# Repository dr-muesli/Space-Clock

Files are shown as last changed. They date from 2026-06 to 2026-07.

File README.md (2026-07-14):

# Space-Clock
**Program code and build guide for the space clock.**

**The space clock is a matrix clock in which the time is determined by counting the number of illuminated light squares.**

---

## Materials

- IKEA Rödalm picture frame (13x18 cm)  
- WS2812B NeoPixel LED strip (60 LEDs/m)  
  - 3 to 5 strips with 9 LEDs each  
- ESP32 (recommended: ESP32-S2 Mini)  
- 3D-printed front panel  
- USB cable compatible with your ESP  

---

## Assembly Instructions

### 1. Prepare the Back Panel

Mark the layout on the back panel of the frame:

- Draw a cross to find the center (vertical and horizontal middle lines)  
- Add additional horizontal lines for each LED row  
- Keep equal spacing between rows (matching the LED spacing)  
- Minimum: **3 rows**  
- Recommended: **5 rows** (for more visual effects)

---

### 2. Attach LED Strips

⚠️ Pay attention to the **data direction** of the LED strips!

- With 5 rows:
  - Start at the bottom row  
  - Attach the strip **from right to left**  
  - Continue each row above in the same direction  

- Solder 3 wires (VCC, GND, DATA) to the **input side** of the bottom strip (left side)

- Connect each strip to the one above it at the ends (daisy chain)

---

### 3. Mount the ESP32

- Attach the ESP32 to the back of the frame  
- Connect:
  - **VCC**
  - **GND**
  - **DATA** (to a suitable GPIO pin)

---

## Programming

*(coming soon)*

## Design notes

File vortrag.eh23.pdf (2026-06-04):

S.p.a.c.e. U.h.r.

# SpaceUhr

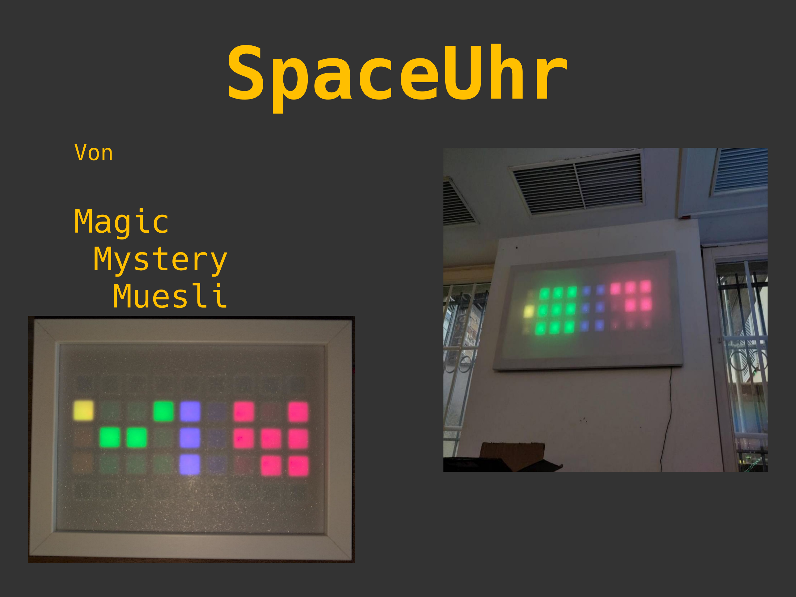
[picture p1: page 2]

Von

## Magic Mystery Muesli

# Magic Mystery Muesli

## - HAXKO - technikbegeisteter Elektroingenieur - PLC, KNX, Softwareentwickung

## - https://woof.tech/@dr_muesli

# butzel

## - HAXKO & LUG-MYK - FIAE & IT-Berater

## - Python, C, Java,VFP

## - GNU/Linux (Gentoo) - Pentester (RedTeamer)

# SpaceUhr

## - Idee nach der Tix-Uhr - alternative Darstellungs-arten

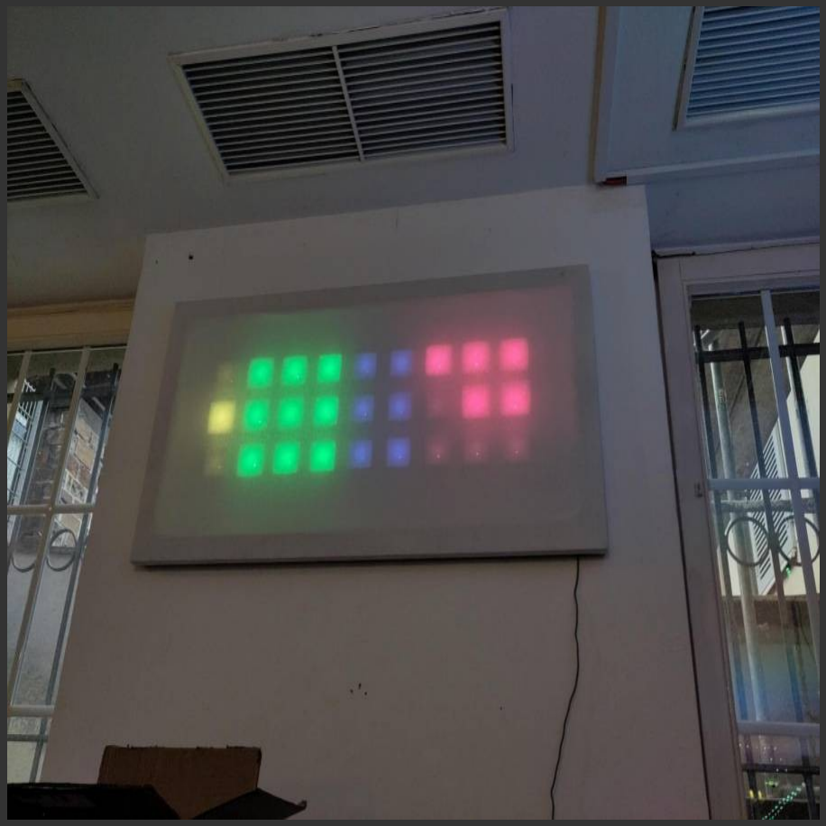
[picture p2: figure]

# SpaceUhr: Funktionsweise

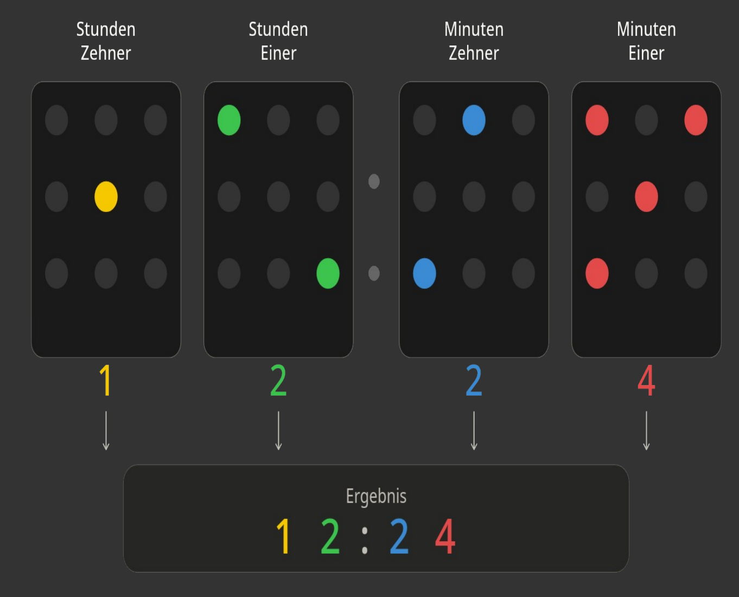
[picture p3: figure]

## - keine BinärUhr - Leuchtpunkte zählen

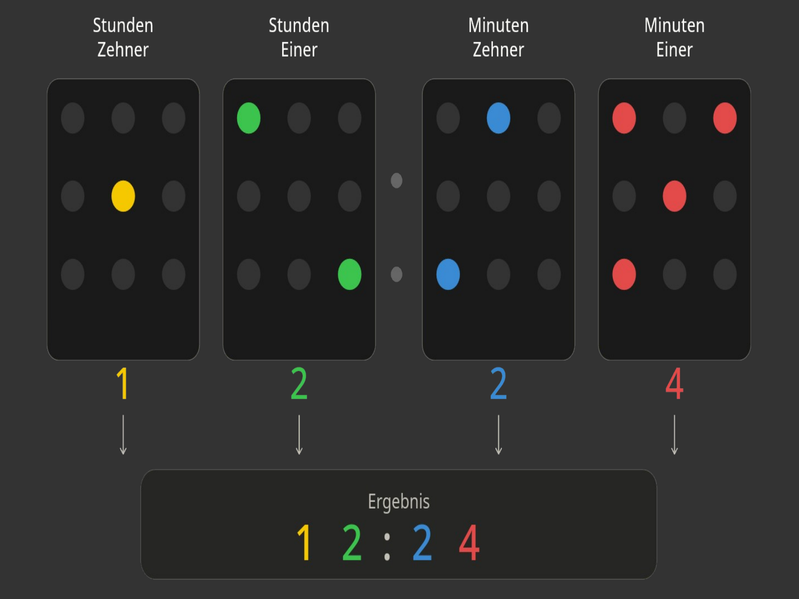
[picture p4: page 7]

# SpaceUhr@EH23

## - verkleinert

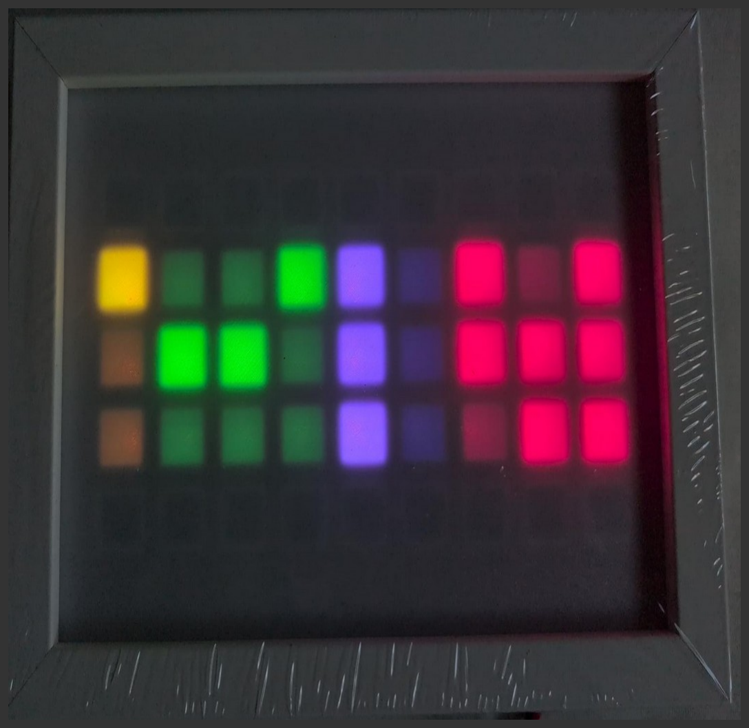
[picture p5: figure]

## - Bilderrahmen „Rödalm“

- 5-zeilig (45 NeoPixel)

## - kein Taster

- ca. 15-20€

# SpaceUhr: BoM

## - Bilderrahmen „Rödalm“

## - 5-Streifen NeoPixel - ESP32 - 3D-Druck - Kabel

# SpaceUhr: Aufbau I

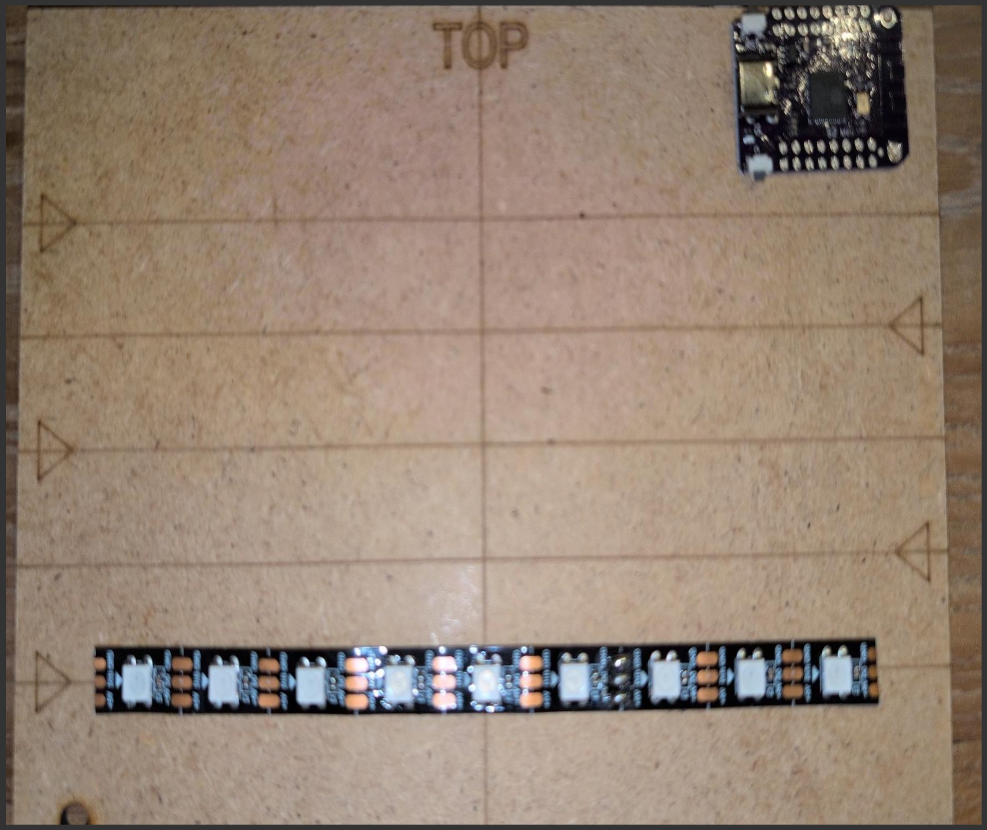
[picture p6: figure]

## - NeoPixel

(selbstklebend)

## - Bilderrahmen

Pfeilrichtung
beachten!

# SpaceUhr: Aufbau I

## - NeoPixel

(selbstklebend)

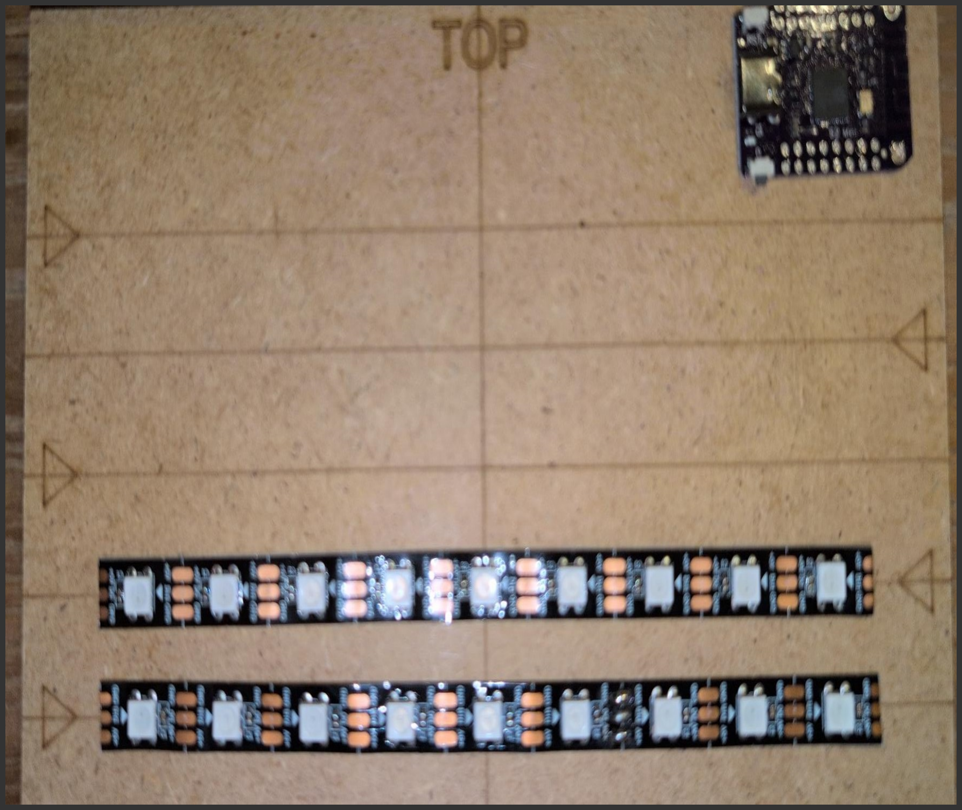
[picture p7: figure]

## - Bilderrahmen

Pfeilrichtung
beachten!

# SpaceUhr: Aufbau II

## - NeoPixel

(selbstklebend)

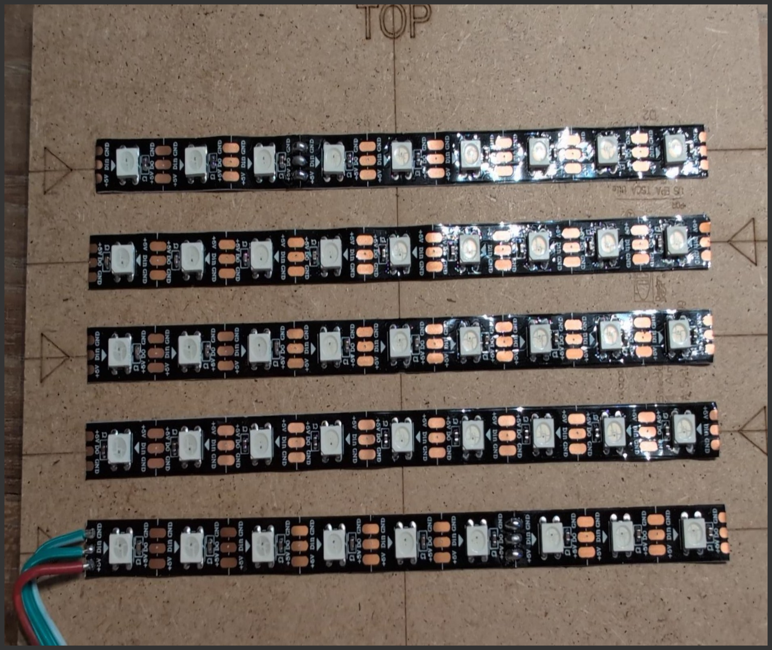
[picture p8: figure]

## - Bilderrahmen - Kabel

Beschriftung
beachten!

# SpaceUhr: Aufbau II

## - NeoPixel

(selbstklebend)

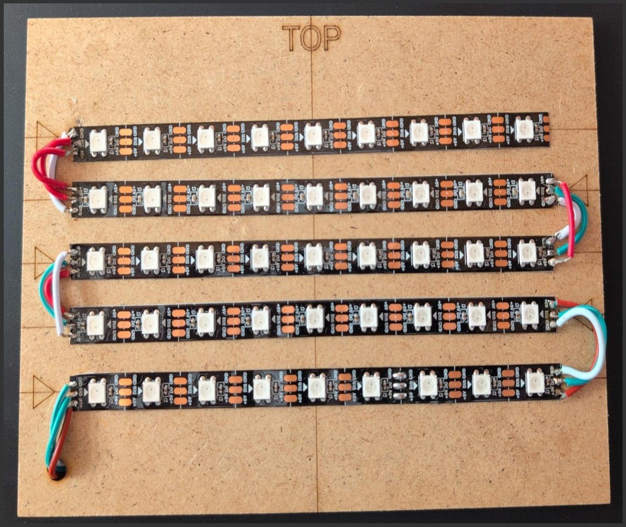
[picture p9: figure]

## - Bilderrahmen - Kabel

Beschriftung
beachten!

# SpaceUhr: Aufbau III

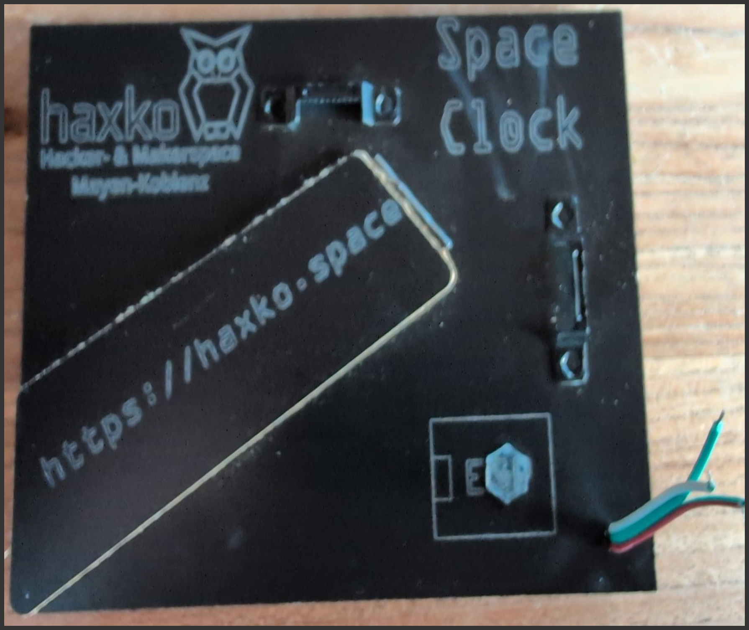
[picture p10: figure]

## - Bilderrahmen - ESP32

Pin 16: DATA
Pin GND: GND
Pin VBUS: 5V

# SpaceUhr: Aufbau III

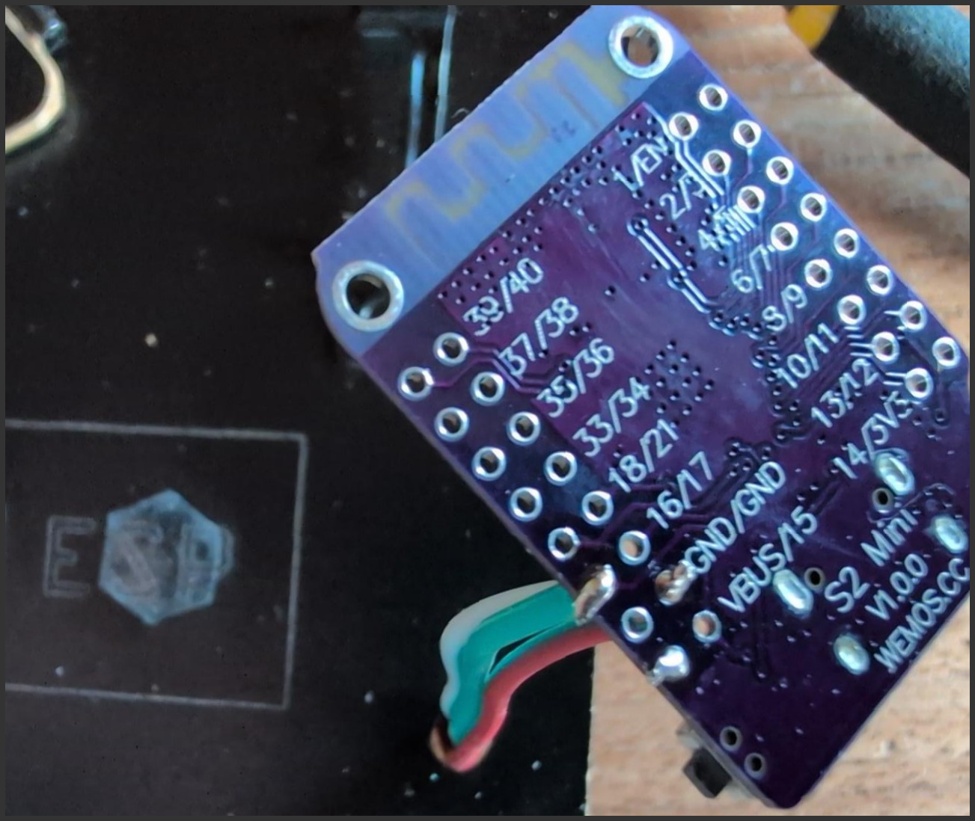
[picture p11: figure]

## - Bilderrahmen - ESP32

Pin 16: DATA
Pin GND: GND
Pin VBUS: 5V

# SpaceUhr: Aufbau III

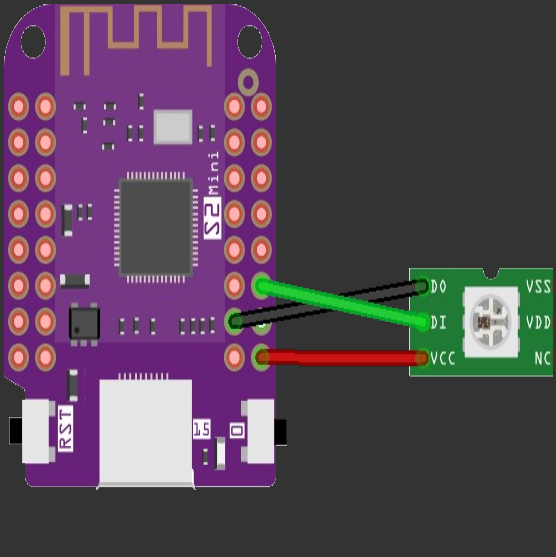
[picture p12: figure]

## - Bilderrahmen - ESP32

Pin 16: DATA
Pin GND: GND
Pin VBUS: 5V

# SpaceUhr: Flashen

## - ESP32 - esptool bzw. esptool.py

# boot-Taster gedrückt halten & USB verbinden

# boot-Taster lösen

esptool --no-stub --port /dev/ttyUSB0 erase_flash
esptool --no-stub --port /dev/ttyACM0 write_flash 0x1000 µpython.bin

# SpaceUhr: thonny

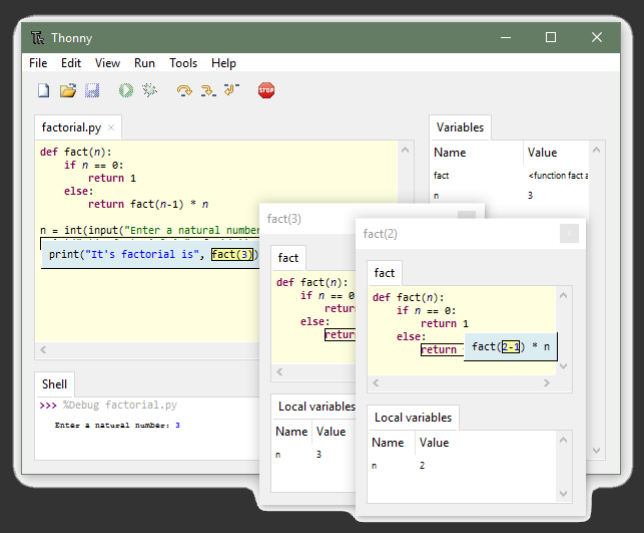
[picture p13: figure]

CC BY-SA 4.0
https://commons.wikimedia.org/wiki/File:Thonny2_0_screenshot_windows_10.pn gg

# SpaceUhr: Programmieren

## - thonny

– Menüpunkt: | run
– Reiter: | interpreter
– DropDown: | MicroPython (ESP32)

### – [strg]+[F2]

# SpaceUhr: main.py

## - thonny

– Menüpunkt: | File/Open
– Dialog: | This computer
– Datei: | main.py

# SpaceUhr: main.py

## - thonny

– Menüpunkt: | File/Save As...
– Dialog: | MicroPython device
– Datei: | main.py

# SpaceUhr: wlan_data.py

## - thonny

– Menüpunkt: | File/Open
– Dialog: | MicroPython device
– Datei: | wlan_data.py

# SpaceUhr: wlan_data.py (anpassen)

## - wlan_data.py

WLAN_NETZE = [
("essid", "<password>"),
("freifunk-myk.de", ""),
("example", "easterhegg2026"), ]

# SpaceUhr: wlan_data.py

## - thonny

– Menüpunkt: | File/Save As...
– Dialog: | MicroPython device
– Datei: | wlan_data.py

# SpaceUhr: MicroPython

## - Erlaeuterung (aus mp-workshop: 11) - Besonderheiten (aus mp-workshop:

27)

## - Flashen (aus mp-workshop: 15) - Verbinden (aus mp-workshop: 31)

●

# SpaceUhr: import abc.py

## - Font-Library: abc.py

import abc

## - setPixel(x, y, rgb, pin)

setPixel(2,4, (7,14,21), 16)

## - write(str, rgb, pin)

write(“Hi“, (7,14,21), 16)

## - marquee(str, rgb, delay, loops, pin)

marquee(“haxko.space“, (7,7,7), 0.2, 5, 16)

# :> MicroPython

:: Python 3
:- Mikrocontroller
:- Embedded Systems

:: Damien P. George
:: 2013 Kickstarter
:: 2014 Release
:: 2016 ESP8266
:: 2016 PyCom (ESP32)
:: 2017 CircuitPython

:: Systemanforderungen
:- 128 KB Flash
:- 8 KB RAM

:: Plattformen
:- unix
:- pyboard
:- stm32f4
:- esp8266
:- esp32
:- Calliope Mini 2.0
:- RP2040 (ARM Cortex M0+) :- ...

# :> Software: esptool.py

:: Flashen von ESP-Chips
:- Installation über PIP:
pip install esptool
:- MAC auslesen:
esptool.py -p /dev/ttyUSB0 -b 115200 read_mac :- Speicher leeren:
esptool.py -p /dev/ttyUSB0 -b 115200 erase_flash :- MicroPython flashen
esptool.py -p /dev/ttyUSB0 -b 115200 write_flash -fm dio --flash_size=8m 0 µpython.bin

# :> Software: Terminal

:: screen
:- screen /dev/ttyUSB0 115200

:: PicoCom
:- picocom /dev/ttyUSB0 -b115200

:: SoCat
:- socat TCP4-LISTEN:8266,fork,reuseaddr /dev/ttyUSB0,raw,crnl,b115200

# :> Software: butzel.net

:: escaper.py [http://files.butzel.net/escaper.tgz]
:- transferiert Dateien
:- reduziert Code
:- kombiniert Imports

:: mptools (fs.py) [http://files.butzel.net/opensource/]
:- Dateisystembefehle
rm, cp, mv, cat, ls
:- Systembefehle
reset, turbo, gc, meminfo, df :- Wlan & Co
ifconfig, wlanap, wscan, i2cscan

# :> MicroPython & Python

## :: Unterschiede :: Grenzen :: Besonderheiten :- boot.py :- main.py :- WebREPL

# :> Flashen von MicroPython

:: Port testen:
dmesg | grep -i uart
[ 3.1337 ] usb 1-1.2: ch341-uart converter now attached to ttyUSB0
:: testen:
esptool.py -p /dev/ttyUSB0 -b 115200 read_mac
:: Speicher leeren:
esptool.py -p /dev/ttyUSB0 -b 115200 erase_flash
:: Flashen von MicroPython
esptool.py -p /dev/ttyUSB0 -b 460800 write_flash –fm dio -fs=detect 0 firmware.bin

# :> Verbindungsaufnahme

:: Connect
screen /dev/ttyUSB0 115200

:- Hallo Welt
>>> print("Hallo Welt!")

:- mehr Hallo Welt
>>> def say_hello():
... print("Hallo")
>>> say_hello()

:: mptools installieren
./escaper.py -rc fs.py -m main.py -d /dev/ttyUSB0

# :> Wlan: Starten

>>> help()

>>> import network
>>> wlan = network.WLAN(network.STA_IF) >>> wlan.active(True)
>>> wlan.scan()

# :> Wlan: Scannen

>>> import network
>>> wlan = network.WLAN(network.STA_IF) >>> wlan.active(True)
>>> for netz in wlan.scan():
... print( str( netz[0], 'ASCII' ) )

scandone

Honigmond

# :> Wlan: Verbinden

>>> import network
>>> wlan = network.WLAN(network.STA_IF)
>>> wlan.active(True)
>>> wlan.connect(b'Honigmond', b'llabdrEWelle')

ip:10.1.1.XX,mask:255.255.255.0,gw:10.1.1.1

# :> Wlan: Konfiguration

>>> import network
>>> wlan = network.WLAN(network.STA_IF)
>>> wlan.active(True)
>>> wlan.connect(b'Honigmond', b'llabdrEWelle')

ip:10.1.1.XX,mask:255.255.255.0,gw:10.1.1.1

>>> wlan.ifconfig()

('IP','Netzmaske','Gateway','DNS')

# :> WebREPL: setup

>>> import webrepl_setup

WebREPL daemon auto-start status: disabled
Would you like to (E)nable or (D)isable it running on boot? (Empty line to quit)
> e

To enable WebREPL, you must set password for it New password (4-9 chars): password

Confirm password: password

Changes will be activated after reboot

Would you like to reboot now? (y/n) y

# :> WebREPL: start

>>> webrepl.start()

WebREPL daemon started on ws://192.168.4.1:8266 WebREPL daemon started on ws://10.1.1.xx:8266

:: WebREPL

:- http://micropython.org/webrepl

WebREPL verbindet direkt zum ESP im lokalen Netzwerk (und nicht über micropython.org ;-)

# :> Credits

:: SpaceUhr
:- Haxko:
:- https://haxko.space

:: Bild von Thonny
:- Wikipedia

:- https://upload.wikimedia.org/wikipedia/commons/d/d4/Thonny2_0_screenshot_windows_10.png (CC BY-SA 4.0)

:: Platinen Bilder
:- Fritzing
:- Adafruit.com

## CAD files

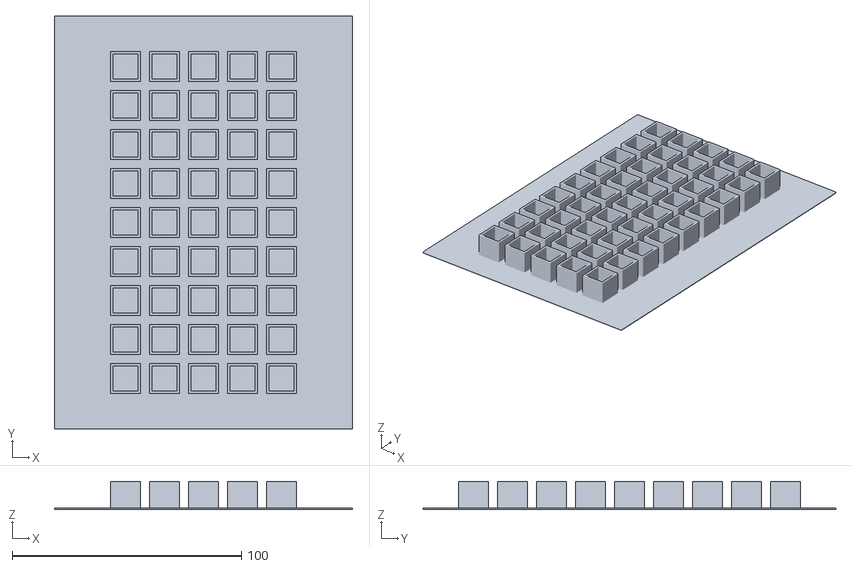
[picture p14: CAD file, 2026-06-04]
Frame5.stl
130.0 x 180.0 x 12.3

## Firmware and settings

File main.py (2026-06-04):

# HAXKO SPACE-UHR // Version für Workshop
#
#
# https://haxko.space/
#
# https://woof.tech/@dr_muesli
#
__author__ = "Magic Mystery Muesli"
__contact__ = "https://woof.tech/@dr_muesli"
__version__ = 20260501
__license__ = "AGPLv3"

from machine import Pin
from time import sleep
from neopixel import NeoPixel
import urandom, random, time
import network, ntptime
import machine, os


# Variablen festlegen:
Farbmodus = 0

m01 = [0, 1, 2, 15, 16, 17, 18, 19, 20]
m02 = [3, 4, 13, 14, 21, 22]
h01 = [5, 6, 7, 10, 11, 12, 23, 24, 25]
h02 = [8, 9, 26]

ofs = 9     # =offset für NeoPixel-Adresse (=0 für 9x3 / =9 für 9x5)

Zeit = "0000"
boot = True
logoakt = False  # (nicht ändern)
synchronisierung = False  # (nicht ändern)
low_light = True
pixeltest = False
WIDTH = 9
HEIGHT = 3


# Konfiguration je nach ESP Modell:
print(os.uname())
info = os.uname().machine.lower()
if "c3" in info:
    print("ESP32-C3-SuperMini erkannt")
    np = NeoPixel(Pin(4), 27)
    taster = Pin(3, Pin.IN, Pin.PULL_DOWN)
elif "s2" in info:
    print("ESP32-S2-mini erkannt")
    np = NeoPixel(Pin(16), 45)       # =27 NP bei 9x3 / =45 NP bei 9x5  (Pin gegebenfalls anpassen)
    taster = Pin(0, Pin.IN, Pin.PULL_DOWN)   # Optionaler Tasteranschluss gegen 3,3V (Pin gegebenfalls anpassen)

    
# Boot-LED Anzeige:
def boot_led(pos, status, sleeping):
    if boot:
        if status == 2:
            np[ofs + pos] = (60, 60, 0)  # gelb
        elif status == 1:
            np[ofs + pos] = (0, 100, 0)  # grün
        else:
            np[ofs + pos] = (100, 0, 0)  # rot
        np.write()
        sleep(sleeping)

print("Hi !")
for x in range(26): np[ofs + x] = (0, 0, 0)
boot_led(0, 1, 0)

sleep(1)  # Sicherheitswartezeit zum reseten bei Fehlern



#---Abschnitt für WLAN und NTP Zeitabfrage (inkl. So/Wi-Zeitumrechnung):

wlan = network.WLAN(network.STA_IF)


#   ! WLAN Zugangsdaten sind jetzt extern hinterlegt auf wlan_data.py
from wlan_data import WLAN_NETZE


def wlan_verbinden():
    for ssid, pw in WLAN_NETZE:
        wlan.active(False)
        boot_led(1, 2, 1.5)
        wlan.active(True)
        print("Versuche Verbindung zu:", ssid)
        wlan.connect(ssid, pw)

        for _ in range(10):  # 5 sekunden warten
            if wlan.isconnected():
                print("Verbunden mit", ssid)
                print("IP-Adresse:", wlan.ifconfig()[0])
                
                # nur aktuelle WLAN verbindung merken für schnellere Syncronisierung:
                WLAN_NETZE[:] = [(ssid, pw)]
                
                boot_led(1, 1, 0)
                return True
            sleep(0.5)

        print("Konnte nicht verbinden:", ssid)
        boot_led(1, 0, 0.2)

    print("Kein WLAN gefunden.")
    return False


def get_dst_offset(year, month, day, hour):

    # Letzter Sonntag im März (beginn Sommerzeit)
    march_last_sunday = max(
        d for d in range(25, 32)
        if time.localtime(time.mktime((year, 3, d, 0, 0, 0, 0, 0)))[6] == 6
    )
    # Letzter Sonntag im Oktober (ende Sommerzeit)
    oct_last_sunday = max(
        d for d in range(25, 32)
        if time.localtime(time.mktime((year, 10, d, 0, 0, 0, 0, 0)))[6] == 6
    )

    # Sommerzeit aktiv? (umstellung basiert auf UTC Zeit!)
    if (month > 3 and month < 10) or \
       (month == 3 and (day > march_last_sunday or (day == march_last_sunday and hour >= 1))) or \
       (month == 10 and (day < oct_last_sunday or (day == oct_last_sunday and hour < 1))):
        return 2  # MESZ (Sommerzeit)
    else:
        return 1  # MEZ (Winterzeit / Normalzeit)


def set_local_time():
    try:
        boot_led(2, 2, 0)
        ntptime.host = "ptbtime3.ptb.de" 	# alternativ: "europe.pool.ntp.org"
        ntptime.settime() 	# RTC auf UTC stellen
        print("NTP Zeit geholt (UTC).")
        
        boot_led(2, 1, 0)
    except Exception as e:
        print("Konnte NTP-Zeit nicht holen:", e)
        
        boot_led(2, 0, 0)
        return False

    # Aktuelle UTC-Zeit
    t = time.localtime()
    year, month, day, hour, minute, second, weekday, yearday = t

    offset = get_dst_offset(year, month, day, hour)

    # Zeitstempel + Offset (lokale Zeit berechnen)
    ts = time.mktime((year, month, day, hour, minute, second, weekday, yearday))
    ts += offset * 3600
    lt = time.localtime(ts)

    # RTC direkt mit lokaler Zeit setzen
    rtc = machine.RTC()
    rtc.datetime((lt[0], lt[1], lt[2], lt[6]+1, lt[3], lt[4], lt[5], 0))
    print("RTC auf deutsche Zeit gesetzt:", rtc.datetime())
    return True



if time.localtime()[0] > 2010:
    print("ESP-Zeit aktuell. Direktstart ohne WLAN und NTP verbindung.")
else:
    if wlan_verbinden():    
        sleep(2.5)
        for x in range(10):
            if set_local_time():
                print("Juhu! Hat alles funktioniert!")
                break
            elif x == 9:
                print("Konnte keine NTP Zeit holen")
            else:
                sleep(2)
    else:
        print("Keine WLAN-Verbindung, keine Zeitabfrage möglich. :(")

wlan.active(False) #WLAN deaktivieren
boot_led(3, 1, 0.5)
boot = False



#---Snake Animation:

# Zickzack-Mapping dank toller NeoPixel anordnung xD :
def idx(x, y):
    if y % 2 == 0:
        return y * WIDTH + (WIDTH - 1 - x)
    else:
        return y * WIDTH + x

def reset_game():
    snake = [(4, 1)]
    dx, dy = 1, 0

    # Ersten Apfel auf freies Feld setzen:
    free_fields = [(x,y) for x in range(WIDTH) for y in range(HEIGHT) if (x,y) not in snake]
    apple = random.choice(free_fields)
    return snake, dx, dy, apple

def snake(Apples = 12):
    global Farbmodus
    snake, dx, dy, apple = reset_game()

    while True:
        head_x, head_y = snake[0]

        # Wunschrichtung Apfel
        preferred = []
        if head_x < apple[0]: preferred.append((1,0))
        if head_x > apple[0]: preferred.append((-1,0))
        if head_y < apple[1]: preferred.append((0,1))
        if head_y > apple[1]: preferred.append((0,-1))
        if not preferred: preferred = [(dx,dy)]

        # Ausweichrichtungen hinzufügen:
        all_moves = [(1,0), (-1,0), (0,1), (0,-1)]
        for m in all_moves:
            if m not in preferred:
                preferred.append(m)

        # Richtung wählen, Kollision vermeiden:
        chosen = None
        for mx,my in preferred:
            nx = max(0, min(WIDTH-1, head_x + mx))
            ny = max(0, min(HEIGHT-1, head_y + my))
            if (nx, ny) not in snake:
                chosen = (mx,my)
                break
        if chosen is None:
            chosen = preferred[0]  # letzte Notlösung

        dx, dy = chosen

        # Kopf bewegen:
        new_x = max(0, min(WIDTH-1, head_x + dx))
        new_y = max(0, min(HEIGHT-1, head_y + dy))
        new_head = (new_x, new_y)

        # Selbstkollision / GameOver:
        if new_head in snake:
            print("Gegessene Äpfel:", len(snake) - 1)
            sleep(1)
            snake, dx, dy, apple = reset_game()
            continue

        snake.insert(0, new_head)

        # Leckeren NeoPixel-Apfel gegessen?:
        if new_head == apple:
            # Einen neuen Apfel auf ein freies Feld setzen:
            free_fields = [(x,y) for x in range(WIDTH) for y in range(HEIGHT) if (x,y) not in snake]
            apple = random.choice(free_fields)
        else:
            snake.pop()
            
        # Rendern/Pixel setzen:
        for i in range(27): np[ofs + i] = (0,0,0)

        ax, ay = apple                      # Apfel
        if len(snake) <= Apples:
            np[ofs + idx(ax, ay)] = (110,8,8) if len(snake)<Apples else (100,100,8)

        for n,(sx,sy) in enumerate(snake):  # Schlange
            np[ofs + idx(sx,sy)] = (8,200,8) if n==0 else (3,70,3)

        np.write()
        
        
        # Letzten/Goldenen Apfel gegessen? / Spiel Gewonnen:
        if len(snake) > Apples:
            print(f"Alle {Apples} Äpfel gegessen")
            sleep(1)
            snake, dx, dy, apple = reset_game()
            if not Farbmodus == 2: break
        

        # Geschwindigkeit / Timer und Tasterabfrage zum Umschalten:
        for _ in range(2):
            sleep(0.09)
            if Farbmodus == 3 and taster.value() == 1:
                Farbmodus = 0
                sleep(0.5)
                return


#---Hauptprogramm Space-Uhr:

# Zufallsgenerator
def rnd(lst, k):
    k = int(k)
    k = min(k, len(lst))  #(nicht mehr ziehen als vorhanden)
    result = []
    pool = lst[:]
    for _ in range(k):
        i = urandom.getrandbits(8) % len(pool)
        result.append(pool.pop(i))
    return result

def modus_haxko():
    for i in range(11):
        
        if i == 1:
            for x in [6, 8, 9, 10, 11, 24, 26]:  #H
                np[ofs + x] = (134, 172, 172)
            np.write()
            sleep(0.3)
        elif i == 3:
            for x in [5, 7, 10, 12, 24]:  #A
                np[ofs + x] = (134, 172, 172)
            np.write()
            sleep(0.3)
        elif i == 5:
            for x in [3, 5, 13, 21, 23]:  #X
                np[ofs + x] = (180, 70, 0)
            np.write()
            sleep(0.3)
        elif i == 7:
            for x in [1, 3, 14, 15, 19, 21]:  #K
                np[ofs + x] = (134, 172, 172)
            np.write()
            sleep(0.3)
        elif i == 9:
            for x in [1, 15, 17, 19]:  #O
                np[ofs + x] = (134, 172, 172)
            np.write()
            sleep(0.3)
        else:
            for x in range(27):
                np[ofs + x] = (100, 100, 100)
            np.write()
            sleep(0.1)

        
        for x in range(27): np[ofs + x] = (0, 0, 0)
        np.write()
        sleep(0.1)
        
        
def modus_rauschen():
    for _ in range(150):
        for x in range(27):
            for z in rnd([0, 1, 2], 1): y =  z * 40
            np[ofs + x] = (y, y, y)
        np.write()
        sleep(0.02)
        
        
def modus_balken(bunt=False):
    for y in range(27):
        np[ofs + y] = (0, 0, 0)
    
    for _ in range(4):
        for i in range(16):
            if i > 8:
                x = 8 - (i - 8)
            else:
                x = i
            
            z = 0
            if bunt == True: z = x + 1
            r = [100, 100, 100, 100, 0, 0, 0, 50, 100, 100]
            g = [100, 0, 50, 100, 100, 50, 0, 0, 25, 100]
            b = [100, 0, 0, 0, 0, 100, 100, 100, 75, 100]
            
            np[ofs + (8 - x)] = (r[z], g[z], b[z])
            np[ofs + (9 + x)] = (r[z], g[z], b[z])
            np[ofs + (26 - x)] = (r[z], g[z], b[z])
            np.write()
            
            # Reset + Schatten für nächste Runde vorbereiten:
            for y in range(27): np[ofs + y] = (0, 0, 0)
                
            np[ofs + (8 - x)] = (r[z] // 5, g[z] // 5, b[z] // 5)
            np[ofs + (9 + x)] = (r[z] // 5, g[z] // 5, b[z] // 5)
            np[ofs + (26 - x)] = (r[z] // 5, g[z] // 5, b[z] // 5)
            
            sleep(0.07)
            
if pixeltest:
    for x in range(len(np)): np[x] = (0,0,0)
    for x in range(len(np)):
        if low_light:
            np[x] = (90,0,0)
        else:
            np[x] = (200,0,0)
        np.write()
        sleep(0.03)
    for x in range(len(np)): np[x] = (0,0,0)
        
        
while True:
    
    #Zeitabfrage mit führender 0 als String
    akt_Zeit = time.localtime()
    stunden = str(akt_Zeit[3])
    minuten = str(akt_Zeit[4])
    if len(stunden) == 1: stunden = "0" + stunden
    if len(minuten) == 1: minuten = "0" + minuten
    if akt_Zeit[0] > 2020:
        Zeit = stunden + minuten
    else:
        Zeit = "1337"
            
    print("Aktuelle Zeit: " + Zeit)
    zeitwerte = [int(c) for c in Zeit]


    if Farbmodus == 0 and low_light:
        # alle LEDs zurücksetzen (gedimmt, aus)
        for x in m01: np[ofs + x] = (7, 1, 1)
        for x in m02: np[ofs + x] = (1, 1, 4)
        for x in h01: np[ofs + x] = (1, 5, 1)
        for x in h02: np[ofs + x] = (6, 3, 1)
        # Zufalls-LEDs setzen
        for x in rnd(m01, zeitwerte[3]): np[ofs + x] = (90, 10, 10)
        for x in rnd(m02, zeitwerte[2]): np[ofs + x] = (20, 20, 80)
        for x in rnd(h01, zeitwerte[1]): np[ofs + x] = (7, 80, 7)
        for x in rnd(h02, zeitwerte[0]): np[ofs + x] = (70, 70, 6)
        np.write()
    elif Farbmodus == 1 and low_light:
        # alle LEDs zurücksetzen (gedimmt, aus):
        for x in m01: np[ofs + x] = (3, 0, 5)
        for x in m02: np[ofs + x] = (0, 1, 4)
        for x in h01: np[ofs + x] = (3, 0, 5)
        for x in h02: np[ofs + x] = (0, 1, 4)
        # Zufalls-LEDs setzen:
        for x in rnd(m01, zeitwerte[3]): np[ofs + x] = (90, 0, 100)
        for x in rnd(m02, zeitwerte[2]): np[ofs + x] = (0, 60, 80)
        for x in rnd(h01, zeitwerte[1]): np[ofs + x] = (90, 0, 100)
        for x in rnd(h02, zeitwerte[0]): np[ofs + x] = (0, 60, 80)
        np.write()
    elif Farbmodus == 2 and low_light:
        for x in range(9):
            if akt_Zeit[5] & (1 << x):
                np[ofs + x] = (10, 70, 10)
            else:
                np[ofs + x] = (0, 0, 0)
            if akt_Zeit[4] & (1 << x):
                np[ofs + 17 - x] = (10, 10, 70)
            else:
                np[ofs + 17 - x] = (0, 0, 0)
            if akt_Zeit[3] & (1 << x):
                np[ofs + 18 + x] = (70, 10, 10)
            else:
                np[ofs + 18 + x] = (0, 0, 0)
        np.write()
    elif Farbmodus == 0:
        # alle LEDs zurücksetzen (gedimmt, aus)
        for x in m01: np[ofs + x] = (10, 2, 2)
        for x in m02: np[ofs + x] = (2, 2, 6)
        for x in h01: np[ofs + x] = (2, 8, 2)
        for x in h02: np[ofs + x] = (8, 5, 1)
        # Zufalls-LEDs setzen
        for x in rnd(m01, zeitwerte[3]): np[ofs + x] = (200, 20, 20)
        for x in rnd(m02, zeitwerte[2]): np[ofs + x] = (50, 50, 160)
        for x in rnd(h01, zeitwerte[1]): np[ofs + x] = (10, 180, 10)
        for x in rnd(h02, zeitwerte[0]): np[ofs + x] = (200, 180, 10)
        np.write()
    elif Farbmodus == 1:
        # alle LEDs zurücksetzen (gedimmt, aus):
        for x in m01: np[ofs + x] = (3, 0, 5)
        for x in m02: np[ofs + x] = (0, 2, 7)
        for x in h01: np[ofs + x] = (3, 0, 5)
        for x in h02: np[ofs + x] = (0, 2, 7)
        # Zufalls-LEDs setzen:
        for x in rnd(m01, zeitwerte[3]): np[ofs + x] = (180, 0, 200)
        for x in rnd(m02, zeitwerte[2]): np[ofs + x] = (0, 150, 200)
        for x in rnd(h01, zeitwerte[1]): np[ofs + x] = (180, 0, 200)
        for x in rnd(h02, zeitwerte[0]): np[ofs + x] = (0, 150, 200)
        np.write()
    elif Farbmodus == 2:
        for x in range(9):
            if akt_Zeit[5] & (1 << x):
                np[ofs + x] = (10, 180, 10)
            else:
                np[ofs + x] = (0, 0, 0)
            if akt_Zeit[4] & (1 << x):
                np[ofs + 17 - x] = (50, 50, 160)
            else:
                np[ofs + 17 - x] = (0, 0, 0)
            if akt_Zeit[3] & (1 << x):
                np[ofs + 18 + x] = (200, 20, 20)
            else:
                np[ofs + 18 + x] = (0, 0, 0)
        np.write()
    

    
    # Warteschleife 4-sekunden mit tasterabfrage für Animation:
    for x in range(40):
        sleep(0.1)
        if taster.value() == 1:
            sleep(0.2)
            if taster.value() == 1:
                modus_haxko()
                modus_balken(True)
                modus_haxko()
            else:
                Farbmodus += 1
                if Farbmodus > 3: Farbmodus = 0
            break
        elif Farbmodus == 2 and x >= 10:  # Sekundentakt für Binäruhr
            break
        
    
        
    # Erweiterte Animationen unter Farbmodus:
    if Farbmodus == 3: snake()

    # Animation und Zeitsynchronisierung:
    if logoakt == False and Zeit == "0000":
        logoakt = True
        sleep(10)
        modus_rauschen()
        modus_balken()
        modus_haxko()
        modus_balken(True)
        modus_haxko()
        
    elif synchronisierung == False and (Zeit == "0201" or Zeit == "0301" or (akt_Zeit[0] < 2020 and minuten[1] == "5")):
        synchronisierung = True
        wlan_verbinden()
        set_local_time()
        wlan.active(False)
        
    elif minuten[1] == "9":
        logoakt = False
        synchronisierung = False
    
